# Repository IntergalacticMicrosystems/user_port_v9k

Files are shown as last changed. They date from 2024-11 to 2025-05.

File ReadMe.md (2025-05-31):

# IntergalacticMicrosystems NOTE:
Will be tweaking this to use plain pico board and USB stdio.

# Victor 9000 User Port SD Card Interface

## Overview

This project enables the Victor 9000 to interface with an SD card via the User Port using a Raspberry Pi Pico. The Pico acts as a bridge between the Victor 9000 and the SD card, allowing MS-DOS 3.1 to read and write files as if it were a standard storage device.

The project consists of:
- 	A custom PCB that connects a Raspberry Pi Pico to the Victor 9000 User Port.
- 	A DOS device driver for MS-DOS 3.1 on the Victor 9000.
- 	Firmware for the Raspberry Pi Pico to handle SD card operations.

⸻

Features
- 	Read and write FAT16/FAT32 formatted SD cards.
- 	Accessible as a drive letter under MS-DOS 3.1.
- 	Uses the Victor 9000 User Port for communication.
- 	Low power consumption – powered directly from the user port.

⸻

Hardware Requirements

Required Components
- 	Victor 9000 running MS-DOS 3.1.
- 	Custom PCB
- 	Raspberry Pi Pico.
- 	SD card slot.
- 	SD card formatted as FAT16 or FAT32.

See the schamtic for Victor 9000 User Port to Raspberry Pi Pico Pin Mapping

⸻

Software Installation

1. Flash the Raspberry Pi Pico Firmware
    1. Connect your Pico to a PC via USB.
    1. Hold the BOOTSEL button and power on the Pico.
    1. Drag-and-drop the compiled firmware (user_port_pico.uf2) onto the RPI-RP2 drive.

1. Install the MS-DOS Device Driver
    1.	Copy the Victor 9000 DOS driver (SDDRV.SYS) to the system drive.
    1.	Edit CONFIG.SYS to include: `DEVICE=userport.sys`

1.	Reboot the Victor 9000.

⸻

Usage

Accessing the SD Card

Once the driver is loaded, the SD card will be assigned a drive letter (e.g., E:). You can then use standard DOS commands:

DIR E:\
COPY C:\FILE.TXT E:\
DEL E:\OLD.TXT

Formatting an SD Card

The SD card must be formatted with FAT16 or FAT32. Use a modern PC to format the card before inserting it into the Victor 9000. You'll also need a Victor formatted disk image loaded on the card.

⸻

Troubleshooting

Driver Not Loading
 - Ensure userport.sys is in the root of your boot disk
 - Check CONFIG.SYS syntax.
 - Verify the Victor 9000 User Port connection.

SD Card Not Detected
 - Ensure the SD card is FAT16/FAT32 formatted.
 - Check the Pico firmware is flashed correctly.
 - Verify the Victor 9000 User Port wiring.
## Credits
 - Hardware & Software Development: Paul Devine
- Many thanks to profdc9 at the VCFED forums who provided the code that got me started you can find it here:
[ https://forum.vcfed.org/index.php?threads/ms-dos-driver-for-an-sd-card-connected-via-a-parallel-port.41516/](url)
- Many thanks to Educardo Casino for his Openwatcom DOS driver [https://github.com/eduardocasino/dos-device-driver](url) which I incorported.
- Victor 9000 Background info and help: Many thanks to Bitsavers, Disk Blitz and the folks at the AppleSauce discord for patiently explaining to me lots of background; FozzTexx for his help in understanding some of the Victor 9000 hardware; FreddyV, Polpo, and the folks at the Retro Pico discord for letting me lurk over their shoulders; and Intergalactic for finding the hard disk struct documentation!

For questions or contributions, feel free to open an issue or submit a pull request.

I'm releasing this under the GPL-v2 as the source code I've incorporated utilized that licensing scheme.

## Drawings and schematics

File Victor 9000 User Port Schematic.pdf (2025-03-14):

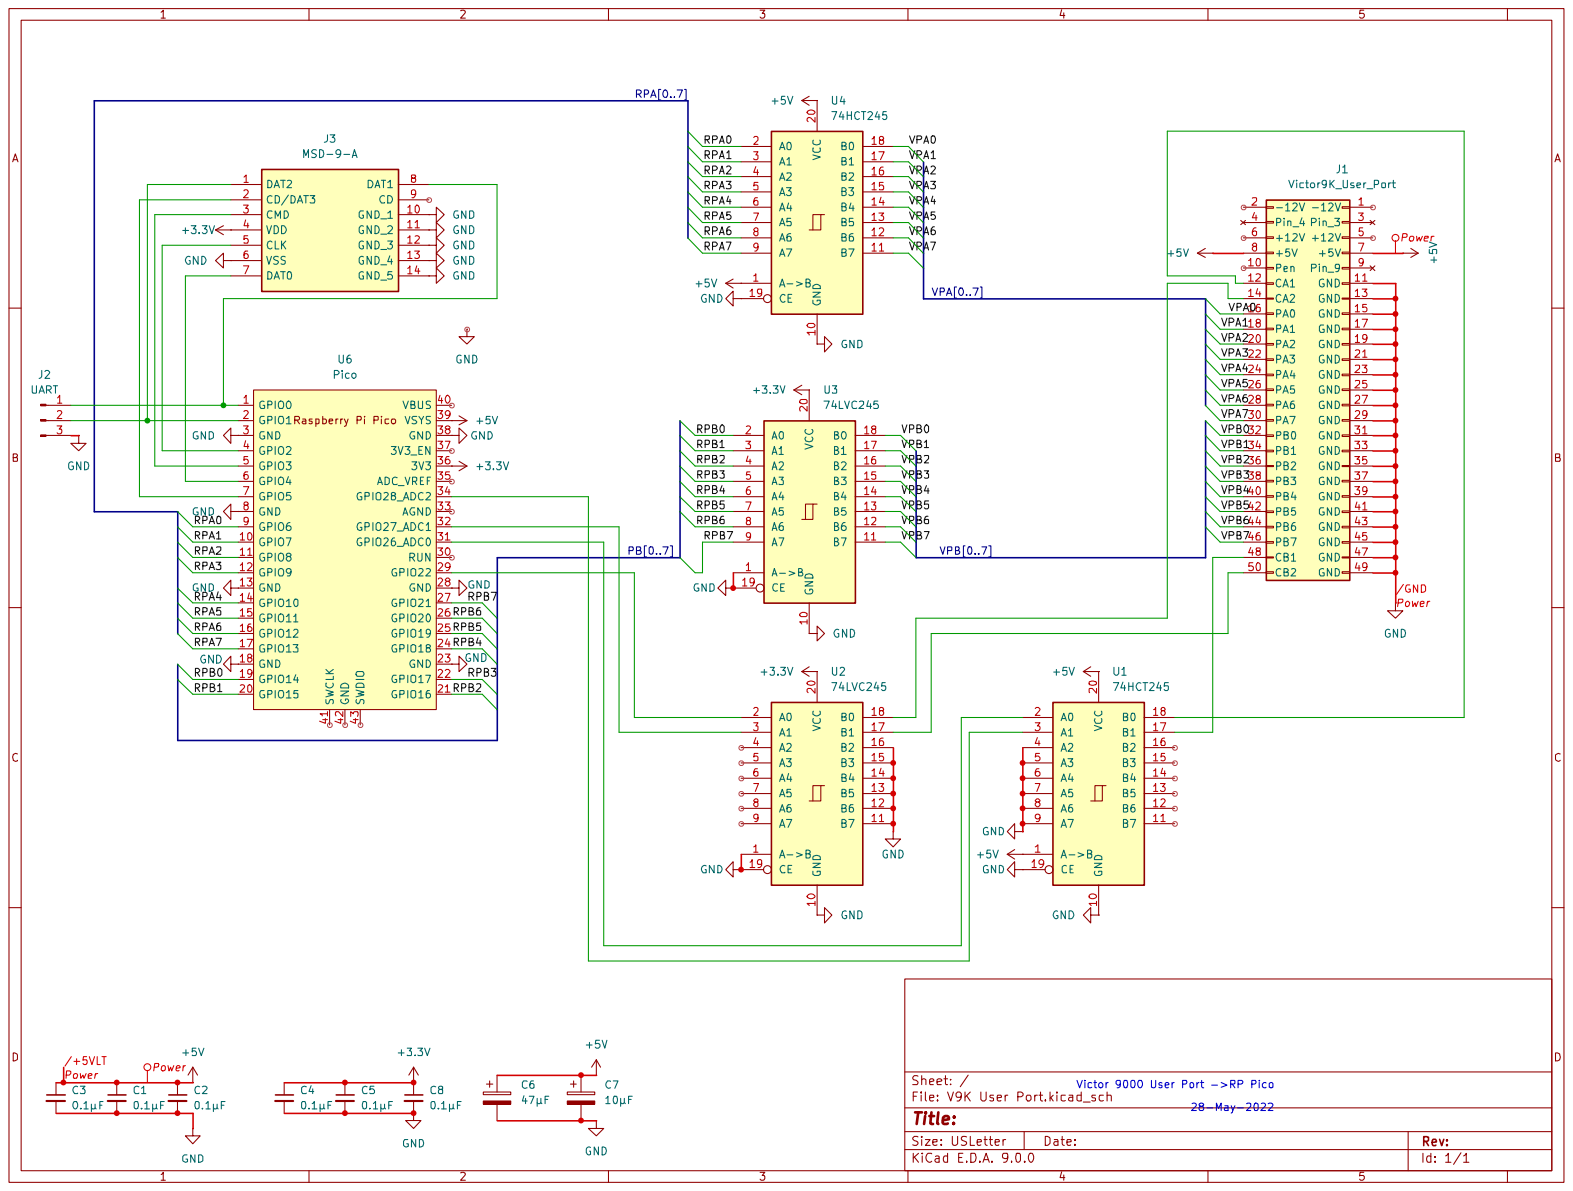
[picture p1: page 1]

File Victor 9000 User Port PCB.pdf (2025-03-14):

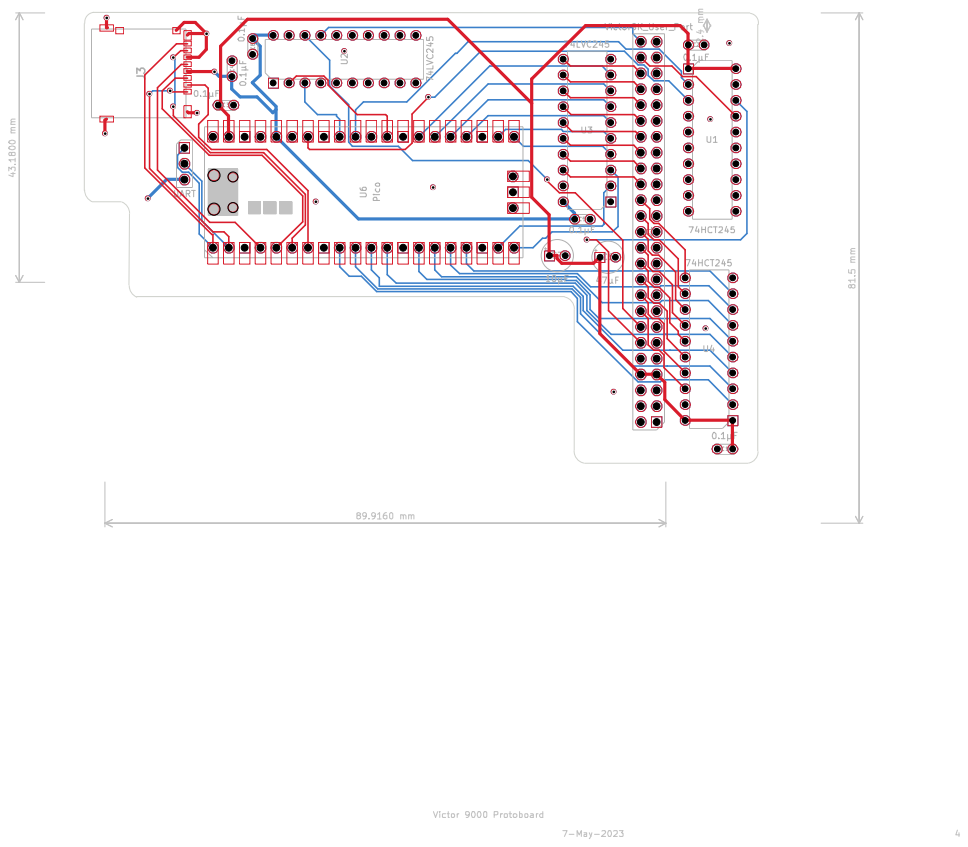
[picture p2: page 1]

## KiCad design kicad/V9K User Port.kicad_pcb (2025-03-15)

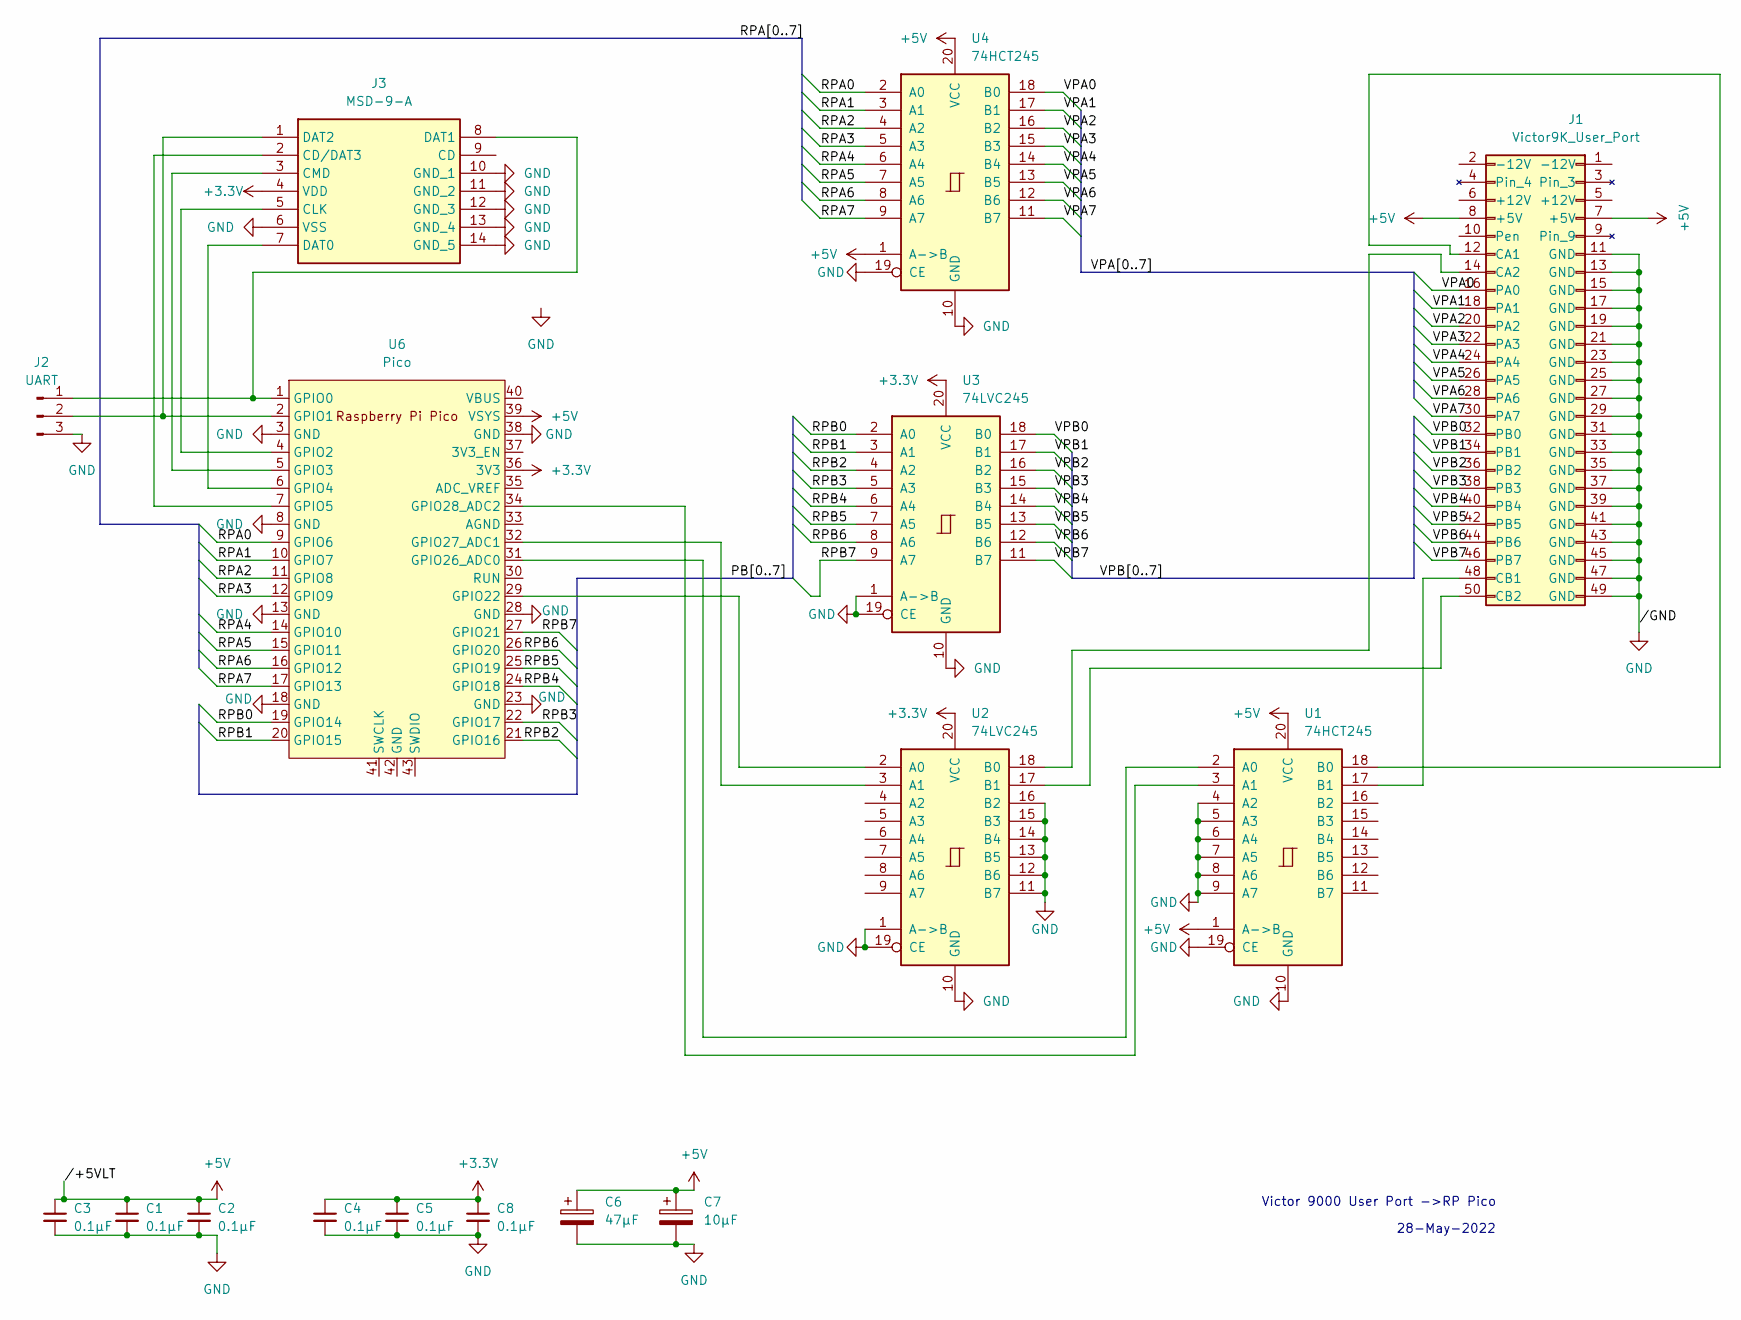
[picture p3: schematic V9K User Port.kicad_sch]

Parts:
C1, C2, C3, C4, C5, C8: 0.1µF; C_Disc_D3.0mm_W1.6mm_P2.50mm
C6: 47µF; CP_Radial_D5.0mm_P2.50mm
C7: 10µF; CP_Radial_D5.0mm_P2.50mm
J1: Victor9K_User_Port; PinHeader_2x25_P2.54mm_Vertical
J2: UART; PinHeader_1x03_P2.54mm_Vertical
J3: MSD-9-A; MSD9A; Manufacturer_Part_Number MSD-9-A
U1, U4: 74HCT245; DIP-20_W7.62mm
U2, U3: 74LVC245; DIP-20_W7.62mm
U6: Pico; RPi_Pico_SMD_TH

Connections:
+3.3V: C4.1, C5.1, C8.1, J3.4 (VDD), U2.20 (VCC), U3.20 (VCC), U6.36 (3V3)
+5V: C1.1, C2.1, C3.1, C6.1, C7.1, J1.7 (+5V), J1.8 (+5V), U1.1 (A->B), U1.20 (VCC), U4.1 (A->B), U4.20 (VCC), U6.39 (VSYS)
/RPA0: U4.2 (A0), U6.9 (GPIO6)
/RPA1: U4.3 (A1), U6.10 (GPIO7)
/RPA2: U4.4 (A2), U6.11 (GPIO8)
/RPA3: U4.5 (A3), U6.12 (GPIO9)
/RPA4: U4.6 (A4), U6.14 (GPIO10)
/RPA5: U4.7 (A5), U6.15 (GPIO11)
/RPA6: U4.8 (A6), U6.16 (GPIO12)
/RPA7: U4.9 (A7), U6.17 (GPIO13)
/RPB0: U3.2 (A0), U6.19 (GPIO14)
/RPB1: U3.3 (A1), U6.20 (GPIO15)
/RPB2: U3.4 (A2), U6.21 (GPIO16)
/RPB3: U3.5 (A3), U6.22 (GPIO17)
/RPB4: U3.6 (A4), U6.24 (GPIO18)
/RPB5: U3.7 (A5), U6.25 (GPIO19)
/RPB6: U3.8 (A6), U6.26 (GPIO20)
/RPB7: U3.9 (A7), U6.27 (GPIO21)
/VPA0: J1.16 (PA0), U4.18 (B0)
/VPA1: J1.18 (PA1), U4.17 (B1)
/VPA2: J1.20 (PA2), U4.16 (B2)
/VPA3: J1.22 (PA3), U4.15 (B3)
/VPA4: J1.24 (PA4), U4.14 (B4)
/VPA5: J1.26 (PA5), U4.13 (B5)
/VPA6: J1.28 (PA6), U4.12 (B6)
/VPA7: J1.30 (PA7), U4.11 (B7)
/VPB0: J1.32 (PB0), U3.18 (B0)
/VPB1: J1.34 (PB1), U3.17 (B1)
/VPB2: J1.36 (PB2), U3.16 (B2)
/VPB3: J1.38 (PB3), U3.15 (B3)
/VPB4: J1.40 (PB4), U3.14 (B4)
/VPB5: J1.42 (PB5), U3.13 (B5)
/VPB6: J1.44 (PB6), U3.12 (B6)
/VPB7: J1.46 (PB7), U3.11 (B7)
GND: C1.2, C2.2, C3.2, C4.2, C5.2, C6.2, C7.2, C8.2, J1.11 (GND), J1.13 (GND), J1.15 (GND), J1.17 (GND), J1.19 (GND), J1.21 (GND), J1.23 (GND), J1.25 (GND), J1.27 (GND), J1.29 (GND), J1.31 (GND), J1.33 (GND), J1.35 (GND), J1.37 (GND), J1.39 (GND), J1.41 (GND), J1.43 (GND), J1.45 (GND), J1.47 (GND), J1.49 (GND), J2.3, J3.6 (VSS), J3.10 (GND_1), J3.11 (GND_2), J3.12 (GND_3), J3.13 (GND_4), J3.14 (GND_5), U1.4 (A2), U1.5 (A3), U1.6 (A4), U1.7 (A5), U1.8 (A6), U1.9 (A7), U1.10 (GND), U1.19 (CE), U2.1 (A->B), U2.10 (GND), U2.11 (B7), U2.12 (B6), U2.13 (B5), U2.14 (B4), U2.15 (B3), U2.16 (B2), U2.19 (CE), U3.1 (A->B), U3.10 (GND), U3.19 (CE), U4.10 (GND), U4.19 (CE), U6.3 (GND), U6.8 (GND), U6.13 (GND), U6.18 (GND), U6.23 (GND), U6.28 (GND), U6.38 (GND)
unnamed: J1.12 (CA1), U1.18 (B0)
unnamed: J1.14 (CA2), U2.18 (B0)
unnamed: J1.48 (CB1), U1.17 (B1)
unnamed: J1.50 (CB2), U2.17 (B1)
unnamed: J2.1, J3.8 (DAT1), U6.1 (GPIO0)
unnamed: J2.2, J3.1 (DAT2), U6.2 (GPIO1)
unnamed: J3.2 (CD/DAT3), U6.7 (GPIO5)
unnamed: J3.5 (CLK), U6.4 (GPIO2)
unnamed: J3.3 (CMD), U6.5 (GPIO3)
unnamed: J3.7 (DAT0), U6.6 (GPIO4)
unnamed: U1.2 (A0), U6.31 (GPIO26_ADC0)
unnamed: U1.3 (A1), U6.34 (GPIO28_ADC2)
unnamed: U2.2 (A0), U6.29 (GPIO22)
unnamed: U2.3 (A1), U6.32 (GPIO27_ADC1)

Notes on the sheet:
Victor 9000 User Port ->RP Pico
28-May-2022

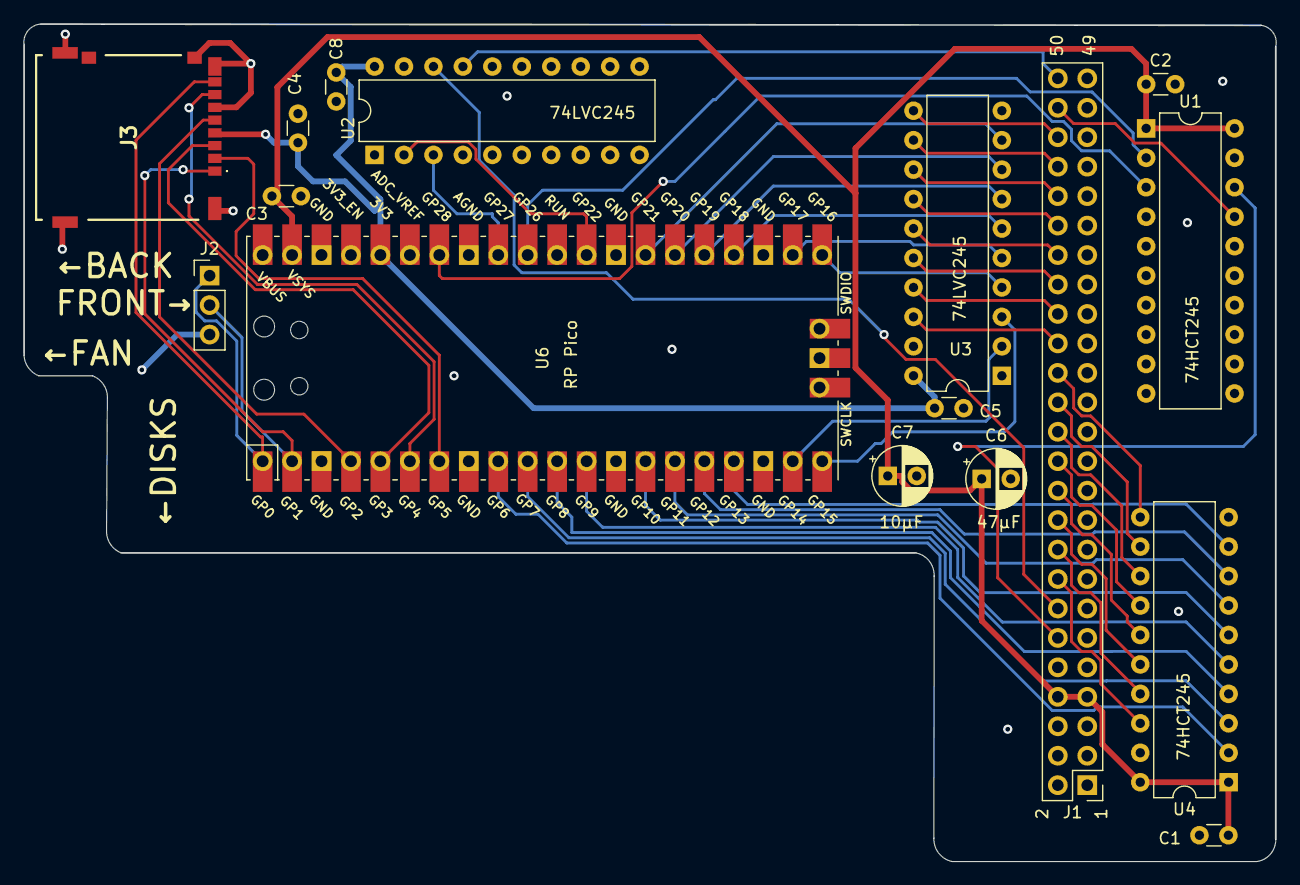
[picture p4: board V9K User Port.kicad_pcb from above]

Board: 4 copper layers, 108.0 x 72.2 mm, 16 parts (0 on the bottom side), 49 nets.

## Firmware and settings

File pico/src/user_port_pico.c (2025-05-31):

#include <stdio.h>
#include <stdlib.h>

#include "pico/stdlib.h"
#include "hardware/clocks.h"
#include "hardware/pio.h"
#include "pico/multicore.h"

#include "user_port_pico.h"
#include "receive_fifo.pio.h"
#include "transmit_fifo.pio.h"
#include "pico_communication.h"
#include "sd_block_device.h"

// Assume pio0 is the PIO instance and sm is the state machine number
// This could be part of your main function or a dedicated function for handling PIO data
void read_from_pio_fifo(PIO pio, uint sm) {
    int count = 0;
    while (true) {
        uint32_t data = pio_sm_get_blocking(pio, sm);
        //printf("Received data: %d FIFO depth: %d\n", data, pio_sm_get_rx_fifo_level(pio, sm));
        if (++count % 100 == 0) {
            printf("Received data: %d FIFO depth: %d\n", data, pio_sm_get_rx_fifo_level(pio, sm));
        }

    }
}

void send_to_pio_fifo(PIO pio, uint sm) {
    uint8_t sendData[200]; // Example sendData to send
    for(int i = 0; i < 200; ++i) {
      sendData[i] = i; // Initialize sendData
    }

    for(int i = 0; i < 200; ++i) {
        bool warned = false;
        while (pio_sm_is_tx_fifo_full(pio, sm)) {
            if (! warned) {
                //printf("Warning: TX FIFO is full, waiting...\n");
            }
            warned = true;
            sleep_ms(1);  // Simple throttling
        }
        //printf("Sending data: %d FIFO depth: %d\n", sendData[i], pio_sm_get_tx_fifo_level(pio, sm));
        if (i % 100 == 0) {
            printf("Sending data: %d FIFO depth: %d\n", sendData[i], pio_sm_get_tx_fifo_level(pio, sm));
        }
        pio_sm_put_blocking(pio, sm, sendData[i]);
    }
}

int main(void) {
    stdio_init_all();

    /*
    uart_init(UART_ID, 115200);  // You can adjust the baud rate here
    gpio_set_function(UART_TX_PIN, UART_FUNCSEL_NUM(UART_ID, UART_TX_PIN));
    gpio_set_function(UART_RX_PIN, UART_FUNCSEL_NUM(UART_ID, UART_RX_PIN));

    // // Redirect stdout to UART
    uart_set_hw_flow(UART_ID, false, false);
    uart_set_format(UART_ID, 8, 1, UART_PARITY_NONE);
    */
    puts("User Port Pico Initializing...");

    // Initialize PIO
    PIO_state *pio_state = init_pio();

    //Initialize the SD Card
    const char *directory = "";
    SDState *sd_state = initialize_sd_state(directory);
    puts("  SD Card initialized.");

    wait_for_startup_handshake(pio_state);
    puts("  Victor startup handshake.");
    process_incoming_commands(sd_state, pio_state);

    return 0;

}

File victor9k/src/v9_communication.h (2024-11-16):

#include "../../common/protocols.h"

#ifndef _USER_PORT_H
#define _USER_PORT_H

#pragma pack(push, 1)
// Serial port control registers
#define INTEL_DEV_SEGMENT 0xE000      // Base address segment for UART control, 7201 serial controller
#define NEC7201_REG_OFFSET 0x0040     // Base address offset for UART control, 7201 serial controller
#define NEC7201_RESET_CMD 0x18        // Channel reset command for the 7201 serial controller in hex
#define NEC7201_CHAR_AVAILABLE 0x01   // Bit mask for character available in 7201 status register
#define NEC7201_TX_BUFFER_EMPTY 0x04  // Bit mask for TX buffer empty in 7201 status register

// Timer control registers, used to control baud rate
#define TIMER_8253_OFFSET 0x0020 // Timer base address offset for baud rate setup
#define CLOCK_8253_FREQUENCY 1250000 // 1.25MHz clock frequency

// Segment for 8259 programable interrupt controller [PIC] used for interrupt handling
#define PIC_8259_OFFSET 0x0000
#define PIC_NON_SPECIFIC_EOI  0x20   //Mask for End of Interrupt
#define PIC_VIA_SPECIFIC_EOI 0x62   //Mask for End of Interrupt

// Constants for setting up the interrupt service routine
#define INTERRUPT_NUM 0x43
#define IVT_ENTRY (INTERRUPT_NUM * 4) // Each Interrupt Vector Table [IVT] entry is 4 bytes


// The keyboard VIA, resgister 1, is located at E804:0001. The appropriate bits are:
//   Bit 0 (PA0) for port A
//   Bit 1 (PAl) for port B
// Thus,bysettingPA0 to zero,the internal clock is enabled for port A;
// setting PA1 to zero will enable the internal clock for port B.
// Setting PA0 or PAl to one will enable the external disabling the internal clock.
#define PHASE2_DEVICE_SEGMENT 0xE800
#define VIA1_REG_OFFSET   0x0020    // via1 for centronics parallel port   
#define VIA2_REG_OFFSET   0x0040    // via2 keyboard, serial params, parallel enable
#define VIA3_REG_OFFSET   0x0080    // via3 user port, GPIO pins on motherboard
#define TALK_ENABLE_H     0x01      // patallel talk-enable line line VIA2 PB0
#define INTERNAL_EXT_A    0x01      // PAO INT/EXTA Serial A internal / external clock select (LOW=INT)
#define INTERNAL_EXT_B    0x02      // PA1 INT/EXTB Serial B internal / external clock select (LOW=INT)
#define SERIAL_A_RING_IND 0x03      // PA2 RIA Serial A ring indicator (J8-22)
#define SERIAL_A_DSR      0x04      // PA3 DSRA Serial A data set ready (J8-6)
#define SERIAL_B_RING_IND 0x05      // PA4 RIB Serial B ring indicator (J9-22)
#define SERIAL_B_DSR      0x06      // PA5 DSRB Serial B data set ready (J9-6)

// Constants for Handshake configuration
#define VIA_PULSE_MODE         0xAA   // Setup CA / CB as pulse lines for read/write
#define VIA_HANDSHAKE_MODE     0x88   // Setup CA / CB as handshake lines for read/write

// Constants for setting up the Shift Register [SR] and interrupts
#define SR_RESET_MODE          0xE3  // Bit mask to clear the SR mode bits
#define SHIFT_OUT_MODE_110     0x18  // Shift out with mode 110
#define SR_INTERRUPT_MASK      0x04  // Bit to enable SR interrupts in int_enable_reg

//Constants for overall 6522 interactions
#define CA1_INTERRUPT_MASK     0x02  // Bit to enable CA1 interrupts in int_enable_reg
#define CA2_INTERRUPT_MASK     0x01  // Bit to enable CA2 interrupts in int_enable_reg
#define CB1_INTERRUPT_MASK     0x10  // Bit to enable CB1 interrupts in int_enable_reg
#define CB2_INTERRUPT_MASK     0x04  // Bit to enable CB2 interrupts in int_enable_reg
#define CA1_CB1_BOTH_INTERRUPT 0x12  // Bit pattern to enable both CA1 and CB1 interrupts for handshake
#define INTERRUPT_ENABLE       0x80  // Bit in the int_enable_reg to turn on interrupts 
#define VIA_CLEAR_INTERRUPTS   0x7F  // Bit pattern to clear entire interrupt register
#define VIA_RESET_AUX_CTL      0x03  // Resets T1/T2/SR disabled, PA/PB latching enabled
#define MAX_POLLING_ITERATIONS 5000  // Maximum number of iterations to poll for interrupt
#define MAX_HANDSHAKE_ATTEMPTS 100   // Maximum number of handshake attempts before timeout

enum ports {PARALLEL, SERIAL_A, SERIAL_B, USER_PORT};


typedef struct {
    uint8_t out_in_reg_b;
    uint8_t out_in_reg_a;
    uint8_t data_dir_reg_b;         // data-direction, reg 'b'
    uint8_t data_dir_reg_a;
    uint8_t timer1_ctr_lo;
    uint8_t timer1_ctr_hi;
    uint8_t timer1_latch_lo;
    uint8_t timer1_latch_hi;
    uint8_t timer2_ctr_lo;
    uint8_t timer2_ctr_hi;
    uint8_t shift_reg;
    uint8_t aux_ctrl_reg;           // auxiliary Ctrl reg
    uint8_t periph_ctrl_reg;
    uint8_t int_flag_reg;           // interrupt flag register
    uint8_t int_enable_reg;         // interrupt enable register
    uint8_t out_in_reg_a_no_hs;     // out-in reg 'a' NO HANDSHAKE
} V9kParallelPort;

/* something about our makefile isn't letting these be linked, defining here */
extern void Enable( void );
#pragma aux Enable = \
    "sti" \
    parm [] \
    modify [];
extern void Disable( void );
#pragma aux Disable = \
    "cli" \
    parm [] \
    modify [];

static void delay_us(unsigned int n);
#pragma aux delay_us = \
    "mov cx, ax", \
    "loopit:", \
    "loop loopit", \
    parm [ax] \
    modify [cx];

#pragma pack( pop )

ResponseStatus initialize_user_port(void);
void interrupt far userPortISR(void);
ResponseStatus send_startup_handshake(void);
ResponseStatus send_uint16_t(uint16_t data);
ResponseStatus sendBytes(uint8_t far *data, size_t length);
ResponseStatus receiveBytes(uint8_t far *data, size_t length);
ResponseStatus send_command_payload(Payload *payload);
ResponseStatus send_command(Payload *command);
ResponseStatus receive_response(Payload *response);
ResponseStatus send_command_packet(Payload *payload);
ResponseStatus send_data_packet(Payload *payload);

#endif

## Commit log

2024-05-25 clearly separating pico dependencies from common code
2024-05-25 additional cleanup of pico code separated from common
2024-06-30 add no-OS-FatFS-SD-SDIO-SPI-RPi-Pico as submodule
2024-06-30 moving test out of pico in order to change c compilter to native one instead of cross compiling pico
2024-09-25 updated CMakeLists for pico 2.0 SDK and pimorono pico plus 2
2024-09-25 added .h file to move UART to 32,33 pins
2024-10-13 removed duplicate pico sdk setups from cmakelists
2024-10-13 filtered out macos . files from valid entries
2024-10-20 refining pico->v9 communication channel, getting BPB plumbed correctly.
2024-10-29 changed device name to userport
2024-10-29 removing print each value
2024-10-31 removing attempt to print data payload
2024-11-10 removing drive_num from device header, not present in V9K
2024-11-25 added initial classes to log things to pico console instead of to victor display
2024-11-25 swapping over a bunch of V9K display output to log on pico
2024-11-28 moved bpb output logging to pico to make debugging easier
2024-12-16 removing volume ID from data structures, the Victor code doesn't have that.
    [device.h]
2025-01-05 moved welcome message to std DOS interrupt function
2025-03-14 adding Schematica and PCB
2025-03-15 adding kicad files
    [V9K User Port.kicad_pcb, V9K User Port.kicad_sch]
2025-05-31 adj for plain pico + USB stdio
